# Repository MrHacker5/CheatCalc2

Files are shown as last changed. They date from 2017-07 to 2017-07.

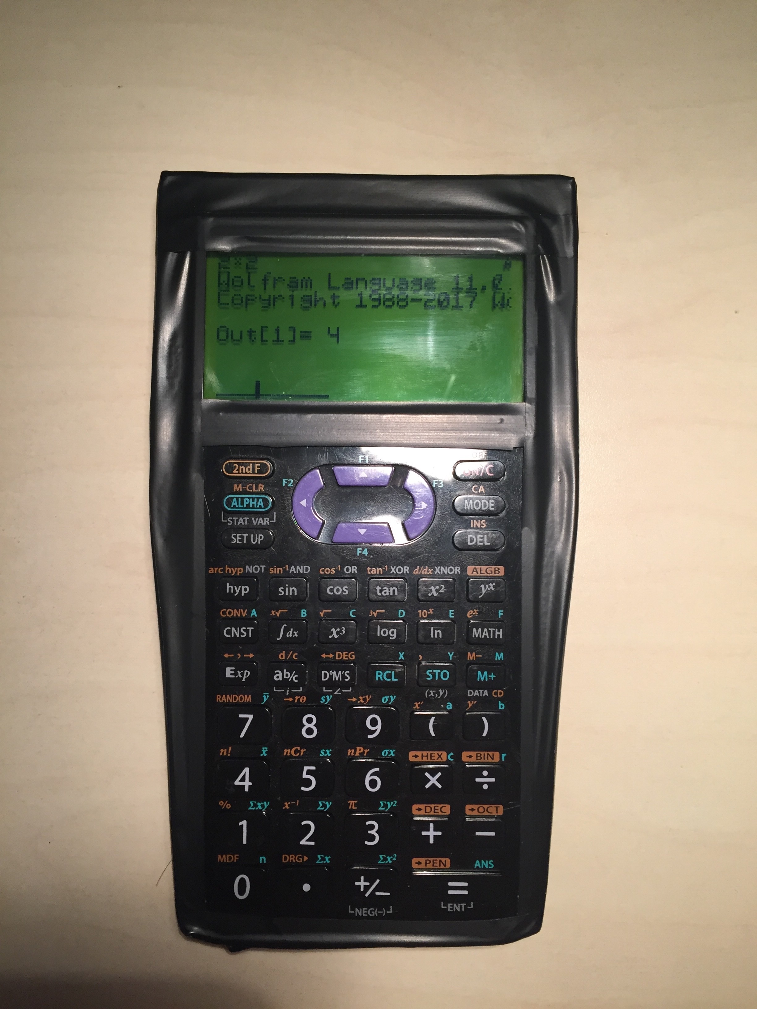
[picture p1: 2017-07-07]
front.JPG

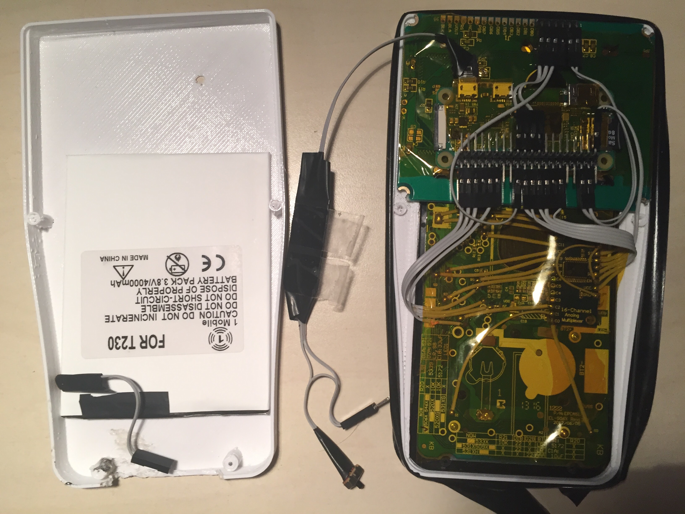
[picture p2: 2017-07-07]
inside2.jpg

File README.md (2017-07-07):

# CheatCalc 2.0
[If the first time ya didn't succeed...](https://github.com/MrHacker5/CheatCalc)

## Features
With this smart calculator you can:  

* solve linear algebra stuff with the help of some macros (ex: eigenSys(m) -> find all eigenvalues and eigenvectors)
* browse input history and use autocompletion
* search previously saved notes by title and tags

## How to build one: Requirements
* Raspberry Pi zero (wireless)
* if you have the rpi zero non wireless you need also a wifi dongle and an OTG adapter
* a calculator with buttons sensors on a PCB (if the sensors are on a plastic sheet, they make too much resistance and the rpi cannot register high signals)
* a graphic LCD (st7920)
* a step-up 3.7V->5V converter
* a Li-Po/Li-ion battery (3.7V)
* a Li-Po battery charger (5->3.7V)
* a multiplexer/demultipllexer 16 to 4
* soldering equipment
* cable-making equipment (ribbon cables, male + female dupont connectors, plastic caps, crimper)
* (angled) male headers
* a 2 state switch
* super glue (cyanoacrylate)
* Kapton (heat resistant) and electrical tape
* a 3D printer to print the calculator case

## Instructions
### Wiring
Extract the pcb from the calculator, desolder the battery holder and isolate the integrated chip on the PCB with a cutter or x-acto knife.  
Follow the circuit paths and map the button layout. It should be equivalent to a grid 4xN (N changes depending of the number of buttons, usually 12-15).  
Connect the PCB pads (if there aren't any, scrape the soldering mask over the circuit paths) corresponding to the paths of the larger side of the grid, to the multiplexer.  
Connect the remaining 4 paths and the input of the multiplexer to the Raspberry Pi. The signal pin of the multiplexer must be grounded.  
Connect the LCD as shown here:  
| LCD pin |  Rpi pin  |  
|  :---:  | :---: |
| RS | 26 (CS0)  |  
| RW | 19 (MOSI) |  
| E | 11 (CLK)  |  
| PSB | GND |  
Please refer to https://github.com/JMW95/pyST7920.  
Connect the Raspberry Pi to the step-up which in turn is connected to the battery (with a switch on the VCC line).  
  
Use the Kapton tape and the electrical tape to isolate the components.  
Print the stl files in the folder `3d files`.

### Installation
You need to use the official distro Raspbian on the Raspberry Pi (this program uses Wolfram Mathematica).  
Install `python3, python-dev, python-rpi.gpio`. Then with pip3 install `pypng`.  
Enable SPI interface with `raspi-config`.  
Clone this repo in the folder `/home/pi/CheatCalc2/`.  
(Optional: download and setup [rclone](https://rclone.org/) to transfer the files from the cloud to the Raspberry.)  
In the file `CheatCalc2/key-layout.txt`:  

* modify the input and output pins according to your wiring
* modify the key function relative to each combination of input-output

Append to `/etc/rc.local` (remember the '&'):  
```sh /home/pi/Cheatcalc2/bootstrap.sh &```  

## Enjoy
Save your own notes in the file `CheatCalc2/notes.txt` and your macros in the file `CheatCalc2/macros.txt`.

## Gallery
![front](/front.jpg?raw=true)
![inside1](/inside1.jpg?raw=true)
![inside2](/inside2.jpg?raw=true)

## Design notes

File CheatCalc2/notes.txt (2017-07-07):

%title: Spazio vettoriale
Un spazio vettoriale e' tale se sono definite le operazioni di somma e prodotto. Es: R2

%title: Sottospazio
%tags: sotto spazio sottoinsieme insieme
Un sottosp di V e' un sottoinsieme U non vuoto di V che e' uno spazio vett per la restrizione delle operazioni si V

%title: Intersezione di sottospazi
Se U e W sono sottospazi di V allora UnW={ v c- V / u c- U e u c- W } e' un sottospazio di V
DIM: UnW  != vuoto perche' contiene 0v sempre. Se v1, v2 c- U n W e alpha, beta c- k
alpha*v1+beta*v2 c- U perche' U e' sottosp
alpha*v1+beta*v2 c- W
quindi appartiene all'intersez, che e' sottosp di V #

%title: Indipendenza lineare
%tags:  vettori indipendenti vett ind
I vett v1...vn di V sono lin ind se a1*v1+...an*vn=0v
quindi a1=a2=an=0
I vett sono dip se uno si puo' scrivere come comb lin dei rimanenti
DIM (=>) v1..vn lin dip se esistono lamb1..lambn tc lamb1v1+..lambn*vn=0v
c'e' qualche lamb_i!=0
lambivi=-lamb1v1-..lambnvn [senza lambivi]
vi=-lamb1/lambi[=a1]*v1-..n=a1v1+..anvn
(<=)...

%title: Base
%tags: generatori indipendenti
base = gen + ind
Oss: Se 'V'={v1...vn} e' una base di V, allora ogni v c- V si scrive in modo unico come comb lin dei vett della base
DIM: V=<v1...vn> quindi dato v c- V esiste a1...an c- K tc v=a1*v1+...an*vn
Se fosse anche v = a1*v1+...an*vn avrei:
0v=v-v=(a1*v1+...an*vn)-(b1*v1+...bn*vn)=(a1-b1)*v1+...(an-bn)*vn
Siccome v1...vn sono ind: a1-b1=...=an-bn=0k #

%title: Equazioni cartesiane
%tags: spazio vettoriale base
Dati v1,...vk base di V sottospazio di Rn, per trovare le eq cart:
Applico le op di Gauss sulla matrice completa (A|b) dove A sono i vettori v messi per riga e b una colonna di coefficienti
Le eq cart sono le espr(=0) corrispondenti alle righe = 0  di A ( quando si arriva a rango minimo)

%title: Teorema di struttura
%tags: dimensioni basi elementi lemma scambio
Ogni sp vett V su K, V!=<0v> ha una base. Due basi di uno stesso sp vett hanno dim uguale. Inoltre V sia finitamente
generato, cioe' esiste un insieme finito di gen per V.
DIM: V!=<0v> 0v non e' lin ind.
Sia V!=<0v> e v1...vn un insieme di gen per V. Ci sono due casi:
- v1...vn sono lin ind -> esiste base #
- v1...vn sono lin dip, quindi a1*v1+...an*vn con non tutti coeff = 0
Posso supporre a1!=0: a1*v1=-a2*vn/a1-...-an*vn/a1  (a1!=0)
Per cui v1 c- <v2...vn> quindi <v2...vn>=<v1,v2...vn>=V
v2...vn sono gen di V, se sono ancora dip ripeto il processo. Siccome V!=<0> quando sono lin ind avro' una base #
DIM due basi hanno uguale dim:
Siano v1...vn e w1...wm de basi di V. In particolare v1...vn sono gen di V e w1... wm sono ind. Per il lemma di scambio m<=n. Ora considero w1...wm gen di V e v1...vn lin ind. Allora per il lemma anche n<=m quindi n=m #

%title: Lemma di scambio
%tags: generatori linearmente indipendenti
Se v1...vn sono gen di V e w1...wr sono vett lin ind allora r<=n. (ogni ins di vett ind puo' essere completato ad una base)
DIM: 0v!=w1 c- <v1...vn>=V
w1=a1*v1+...an*vn con non tutti coeff = 0
A meno di camb l'ordine dei vett v1...vn, supponiamo a1!=0:
v1=w1/a1-a2*v2/a1-...-an*vn/a1
Dunque <w1,v2...vn> _D <v1,v2...vn>=V e percio':
w2 c- V=<w2,v2...vn>
w2=b1*w1+...bn*vn con non tutti coeff=0
a meno di non camb ordine suppongo b2!=0
Quindi v2=w2/b2-b1*w1/b2-b3*w3/b2-...-br*wr/b2
Come prima: V=<w1,v2...vn> c_ <w1,w2,v3...vn> c_ V
overo V=<w1,w2,v3...vn>
Il processo continua fino ad esaurire tutti gli ind w1...wr
Se fosse n<r avrei V=<w1...wn> e w_(n+1) c- <w1...wn> e w1...w_(n+1) sono indipendenti -> assurdo #

%title: Somma di due sottospazi
U+W={u+w/u c- U, w c- W} La somma di sue sottosp e' un sottosp di V ed e' il piu' piccolo sottosp che contiene sia U che W, ovvero U+W=<UuW>
DIM: U+W e' un sottosp perche' non vuoto, 0 c- U, 0 c- W e quindi 0+0=0 c- U+W e dati u1+w1 e u2+w2 in U+W, a1,a2 c- K
a1(u1+w1)+a2(u2+w2)=(a1*u1+a1*w1) [c- U] +(a2*u2+a2*w2) [c- W] c- U+W
Quindi UuW c_ U+W e ogni sottosp che contenga i vett di U e quelli di W, se e' sottosp deve contenere le loro somme #

%title: Somma diretta
%tags: sottospazi
Due sottosp sono in somma diretta se la loro intersezione non e' banale: U1(+)U2 se U1nU2=<0> (!=vuoto)
Ogni vettore U1(+)U2 si scrive in modo unico come somma di un vett di U1 e un vett di U2
DIM: Sia u1+u2=u1'+u2' c- U1(+)U2 con u1,u1' c- U1; u2,u2' c- U2
Allora u1-u1' [c- U1] =u2'-u2 [c- U2]
Cioe' u1-u1'=u2'-u2 c- U1nU2=<0v> perche' un somma diretta
Quindi u1-u1'=0v=u2'-u2
Percio' ui=u1' e u2=u2' #

%title: Formula di Grassmann
Se U e W sono sottosp di uno sp vett V su K: dim(U+W)+dim(UnW)=dimU+dimW
DIM: Sia v1...vr una base di UnW
Per il lemma di scambio posso completare questi vettori ad una base v1...vr,u_(r+1)...us di U; v1...vr,w_(r+1)...wt di W
dim(UnW)=r, dimU=s, dimW=t
v1...vr,u_(r+1)...us,w_(r+1)...wt sono generatori di U+W perche' dato U+W -D u+w=(sum(xn*vn, n=1->r)+sum(xn*un, n=r+1->s))+(sum(yn*vn, n=1->r)+sum(yn*wn, n=r+1->t))=sum((xn+yn)vn, n=1->r)+sum(xn*un, n=r+1->s)+sum(yn*wn, n=r+1->t)
v...u...w sono lin ind perche' dato sum(an*vn, n=1->r)+sum(bn*un, n=r+1->s)+sum(cn*wn, n=r+1->t) = 0
allora [term con a e b = - term con c] => term con b  e c =0 perche' UnW si scrive in modo unico come comb lin di v1...vr
Quindi a1v1+...arvr=0 e' possibile sse tutti gli a=0 perche' v1...vr sono lin ind. Percio' i vett v...u...w sono lin ind.
Quindi v...u...w e' una base di U+W. Percio' dim(U+W)=s+t-r -> dim(U+W)=dimU+dimW-dim(UnW) #

%title: Applicazioni lineari
Se f:V-> W e' lineare allora f(0v)=0w
DIM: f(0v)=f(0v+0v)=f(0v)+f(0v) [f e' lineare]
Sommo -f(0v) ad ambo i membri e trovo 0w=f(0v) #

%title: Isomorfismo
%tags: applicazione lineare biiettiva
Un appl lin e' in isom se esiste un'appl lin g:W->V / f(g(w))=w per ogni w c- W e g(f(v))=v per ogni v c- V
f@g e' l'identita' su w e g@f e' l'identita' su V
isomorfismo<=>biiettiva

%title: Omomorfismo
Applicazione lineare generica.

%title: Endomorfismo
Isomorfismo che ha lo spazio di partenza e di destinazione uguali

%% altro sul pdf 9

%title: Nucleo
%tags: kernel sistema associato
Una base del ker si trova risolvendo il sis associato ad: A*x=0 e assegnando valori arbitrari alle variabili non definite

%title: Proprieta' nucleo e immagine
%tags: kernel
Sia f:V->W appl lin:
- ker f e' sottosp vett di V e Im f e' sottosp vett di W
DIM: 0v c- ker f e se v1, v2 c- ker f e a1,a2 c- KerAf(a1v1+a2v2)=a1(f(v1))+a2(f(v2)) perche' f appl lin
=a1*0w+a2*0w=0w
Dunque a1v1+a2v2 c- ker f = sottosp
0w=f(0v) c- Im f
Se prendo due vett w1,w2 c- Im f e a1,a2 c- K
w1=f(v1), w=f(v2) con v1,v2 c- U1 e quindi a1w1+a2w2 = a1*f(v1)+a2*f(v2)=f(a1v1+a2v2) c- Im f
Quindi f e' sottosp vett #
f e' iniettiva <=> ker f = <0v>
DIM (=>) Se f iniettiva e v!=0v allora f(v)!=f(0v)=0w e quindi ker(f)=<0v> #
(<=) Se f(v1)=f(v2) con v1!=v2 (f non iniettiva) allora f(v1-v2)=f(v1)-f(v2)=0w
quindi 0v!=v1-v2 c- ker f #

%title: Immagine
%tags: rango rk gauss
Le col di A sono i gen della f associata. Una base dell'Im sono i vett corrisp ai pivot trovati con gauss (colonne)
Oppure scelgo ad occhio le colonne lin ind della matrice

%title: Formula delle dimensioni
%tags: kernel immagine nucleo
dim(ker f)+dim(Im f)=dim V
DIM: Siam k=dim(ker f) e siano v1...vk una base di ker f
Completiamo questi vett ad una base v1...vk,v_(k+1)...vn
applicando f ho f(v1)=f(vk)=0w
e siano w_(k+1)=f(vk+1),...,wn=f(vn)
Sia w=f(v) c- Im f con v=x1*v1...xn*vn c- V
Generatori? w=f(sum(xi*vi, i=1->n))=sum(xi*f(vi), i=1->k)[<-barrato] +sum(xi*f(vi), i=k+1->n)=0w
Quindi w c- <w_(k+1)...wn>=Im f
Indipendenti? 0w=a_(k+1)*w...->n= a*f(v) k+1...n=f(a*v, k+1->n)
cioe' a_(k+1)*v...->n c- ker f
e quindi “ =a*v 1->k perche' v1...vk e' base di ker f
dunque v1...vk...vn e' base di V; tutti i coeff sono=0, quindi w_(k+1)...wn ind
Dunque sono base di Im f #

%title: Proprieta' applicazioni lineari
a) Se f:V->W e' lin, f e' univoc det da f(v1)...f(vn)
b) Scelti comunque w1...wn c- W, esiste ed e' unica l'appl lin g:V->W tc g(v1)=w1...g(wn)=wn
DIM a): Sia v c- V. Allora v=x1v1+...xnvn con x1...xn univoc det
Allora f(v)=f(x1v1+...n)=x1*f(v1)+...n
Quindi f(v) e' univoc det dai vett f(v1)...f(vn) #
DIM b): Fissiamo w1...wn c- W consideriamo l'appl che manda v=x1v1+...n c- V in g(v)=x1w1+...xnwn
Devo verif che g sia lin
Se v=x1v1+...n
v'=x1v'1+...n e a,a' c- K
av+a'v'=(ax1+a'x1')v1+...n
g(av+a'v')=(ax1+a'x1')w1+...n=a(x1w1+...n)+a'(x'1w1+...n)=a*g(v)+a'*g(v')
Cioe' g(v1)=w1...g(vn)=wn #

%title: Rango
%tags: rk gauss
rk(A)= dim del sottosp gen dalle col di A =rk(f) (in genere anche =dim(Im f))
rk(AB)<=rk A, rk B
Si puo' trovare con le op di gauss

%title: Nullita'
null(A)=dim(KerA)=dim{x / A*x=0}

%title: Matrice invertibile
matrice A c- Mmxn(K) e' invertibile:
- a dx se esiste B c- Mnxm(K) tc AB=1m; se n<m, rk(AB)<m IMP
- a sx se esiste C c- Mnxm(K) tc CA=1m; se m<n IMP
- invertibile se esiste A^-1 tc A*A^-1=1 o se ker A = <0>; m=n; appartengono al General Linear Group, di ordine n
A nxn non e' invertibile se rk(A)<n

%title: Matrice di cambiamento di base
%tags: canonica
alpha_v'w'(f)=alpha_ww'(id)*alpha_vw(f)*alpha_v'v(id)
id=endomorfismo
Date le basi B={v1...vn} e B'={v'1...v'n}:
Trovare matrice M_B,B':
vj=aj1*v'1+...ajn*v'n per j=1->n. i coeff si trovano risolvendo gli n sistemi (spesso ad occhio).
M_B,B'=[[a11,a21...][a12...]...] (i coefficienti vanno messi per colonna!)
Date la base B e la base canonica C:
M_B,C e' la matrice avente per colonne le coordinate dei vettori di B
M_C,B=(M_B,C)^-1 oppure metodo normale

%title: Operazioni di Gauss
%tags: inversa pivot
Op di Gauss sulle righe equivalgono a cambiamenti di base del codominio
Con le op di gauss sulle righe si puo' trovare l'inversa: (A|1)~(1|A^-1)
Pivot: primo elemento non nullo della riga

%title: Teorema di Rouche'-Capelli
%tags: gauss sistema lineare R-C
Un sis lin si puo' scrivere come (A|b). Con le op di gauss si arriva a (1|s) dove s e' sol particolare e sommato alla comb lin del ker ottengo l'insieme di sol.
Il sis lin Ax=b con A c- M_mxn(K), b c- K^n ha sol <=> rk(A=rk(A|b)
Il sis ha come sol un sottosp di K^n di dim=n-rk A. La sol di un sis lin e' un sottosp vett <=> Il sistema e' omogeneo (b=0)
DIM: Risolvere il sis Ax=b significa trovare S={gamma c- K^n / f(gamma)=b}=f^-1(b) cioe' controimmagine di b
Allora S= (vuoto se b non c- im f) or (se gamma0 c- K^n e' tc f(gamma0)=b allora S=gamma0+ker f)
Se ker(f)=0 e b c- Im f il sis ha 1 sol
Im f c_ K^n e' il sottosp gen dalle col di A
Quindi b c- Im f <=> rk A=rk(A|b) #

%% pdf 20 domande a risp aperta

%title: Determinante
%tags: gauss laplace
E' una funzione multi-lineare;
- si annulla se 2 colonne sono uguali
- matrice id -> =1
- se e' !=0 la mat e' invertibile (rk max)
- det A=det(A^t)
- det(mat triang)= prodotto termini diagonale
Formula di Laplace:
det A= sum(a_ij*(-1)^(i+j) *det(A_ij), j=1->n)
Op di gauss:
- scambio due righe -> det * -1
- moltipl riga per scalare c -> det * c
- somma di righe -> det invar

%title: Teorema di Binet
%tags: determinante
det(AB)=det A * det B

%title: Matrice inversa
%tags: gauss complemento algebrico
Con gauss: (A|1)~(1|A^-1)
Con il det: (A*^t)/det A
Compl agebrico a*_ij: (-1)^(i+j) * det(A_ij) con A_ij la matrice A senza riga i e col j

%title: Matrici simili
%tags: polinomio caratteristico
A, B quadrate sono simili se esiste P c- GLn(K) tc B=P^-1*A*P
Se A e B sono simili allora hanno lo stesso pol. caratt.: det(x*1n-A)=det(x*1n-B)
DIM:det(x*1n-B)=det(x*1n-P^-1*AP)=det(x*P^-1*1nP-P^-1*AP)=det(P^-1 (x1n-A)P)=[binet] det(P^-1) [barrato] det(x1-A) detP [barrato] #

%title: Matrice diagonale
Matrice aventi termini non nulli solo sulla diagonale

%title: Autovalori e autovettori
%tags: matrice diagonale autospazi molteplicita'
Sia V sp vett di dim n e phi:V->V lin
Uno scalare a c- K e' autovalore per phi se esiste un vett v!=0 tc phi(v)=a*v
In tal caso v e' autovettore per phi relativamente ad a
Gli autovettori/autospazi si trovano con ker(A-a*id)=0 dove a e' l'autovalore
Proprieta':
a) autovett di phi relativi ad autoval distinti sono lin ind (ker(phi-a1*id)+...ker(phi-an*id)=0v)
b) per ogni autoval a di phi: m_g(a)<=m_alg(a)
DIM a): Siano v1...vr autovett rel ad a1...ar (a2a2 distinti)
Sia c1v1+...crvr=0v
e Applichiamo (phi-a1*id) ai due membri:
c1(phi(v1)-a1*id*v1)+...cr(phi(vr)-a1*id*vr)=0v
c1(a1-a1)[barrato]*v1+...cr(ar-a1)vr=0
Applico phi-a2,...phi-a_(r-1) e trovo
cr(ar-a1)[!=0]*...(ar-a_(r-1))[!=0][!=0 perche' sono autoval distinti]*vr[!=0]=0
quindi cr=0
Analogamente c1...c_(r-1)=0
DIM b) Sia a autoval per phi e siano v1...vk base di ker(phi-a)={v c- V / phi(v)=a*v}
1<=m_g(a)=k
completiamo i vettori a v1...vk,v_(k+1)...vn base di V
A=alpha_'V''V'(phi)=
(a .. 0 |  )
(...... | B)
(0 .. a |  )
--------+---
(0 .. 0 | C)
P_phi(x)=det(x*1n-A)=det di:
(x-a .. 0|   )
(........| -B)
(0 .. x-a|   )
---------+----
(0 .... 0|x-C)
[x-C ha di (n-k)*(n-k)]
=(x-a)^k*phi(x)
Allora m_alg(a)>=k=m_g(a) #

%title: Matrice diagonalizzabile
%tags: diagonale endomorfismo autovettori autovalori
A c- Mn(K) si dice diagonaliz se esiste una P c- GLn tc P^-1*A*P=D (diagonale)
P e' formato dagli autovett messi in colonna
D e' formato dagli autoval messi sulla diagonale
Un endomorf phi:V->V si dice diagonaliz se esiste una base di V fatta di autovett per phi

%title: Teorema di Freobernius
%tags: molteplicita' algebrica geometrica
Sia V sp vett di dim finita su K e ph:V->V lin
Allora phi e' diagonaliz su K <=> gli autovalori di phi sono tutti in K o per ogni autoval a m_g(a)=m_alg(a)
DIM: Siano a1...ar autoval  a due a due distinti di phi
ker(phi-a1) (+)...(+) ker(phi-ar) c_ V
ha dimensione: mg(a1)+...mg(ar) [ogni termine <= a] ma(a1)+...ma(ar)=dimV #

%title: Prodotto scalare
E' una funzione bilineare e definita positiva

%title: Disuguaglianza di Cauchy-Schwartz:
Se v e w sono vett di R^n allora |v.w|<=||v||*||w||
l'uguaglianza vale <=> v,w sono lin ind
DIM: Se uno dei due e' =0 #
se entrambi !=0 e il vett v+t*w, t c- R allora:
0<=(v+tw)(v+tw)=v.v + 2T(v.w)+t^2(w.w)
0>=delta/4=(v.w)^2-(v.v)(w.w)
allora ||v||^2*||w||^2>=|v.w|^2
cancellando i quadrati -> #

%title: Disuguaglianza triangolare
||x+y||<=||x||+||y||
DIM: ||x+y||^2=(x+y)(x+y)=x.x+2xy+y.y=||x||^2+||y||^2+2xy<=...+2|xy|<=[C-S] ... +2*||x||*||y||=(||x||+||y||)^2
cancellando i quadrati -> #

%title: Vettori ortogonali
%tags: perpendicolari prodotto scalare
v, w c- R^n sono ortog se v.w=0
Se v c- R^n: V^perp={w c- R^n : w.v=0, perogni v c- V} e' sottosp vett di R^n
DIM: siano w1,w2 c- V^perp e alpha1, alpha2 c- R
(a1*w1+a2*w2).v=a1(w1.v)+a2(w2.v)=a1*0+a2*0=0
percio' V^perp e' sottosp #
Vale anche per gli spazi vett
Se W e' sottosp di Rn di dim k allora dim_R(W^perp)=n-k
DIM: Siano w1...wk base di W
w1=(a11...an1)...wk=(a1k...ank)
x=(x1...xn) c- W^perp <=>
/{x.w1=0
...
\{x.wk=0
[sviluppo sistema]
per il T di R-C la dim di W^perp e' n-rk{mat degli a}=n-k perche' w1...wk sono lin ind #
Conseguenza: (W^perp)^perp=W

%title: Teorema di decomposizione ortogonale
%tags: grassmann somma diretta perpendicolari
Preso comunque un sottosp W di R^n:
R^n=W(+)W^perp
DIM: Sia k=dim_R(W). Dunque n-k=dim(W^perp) [vedi DIM in “vettori orogonali”] e per la formula di grassman e' sufficiente DIM che WnW^perp=<0>
Se x c- WnW^perp: x.x=0 => x=0 #

%title: Base ortogonale e ortonormale
Una base ortogonale in W c- Rn e' una base w1...wk c- W dove i vett sono a due a due ortogonali
Una base ortonormale e' una base ortogonale di W tc ||w1||...||wk||=0
Se 'V'={v1...vn} e' base O.N. in R4
P=alpha_'V''E'(id) allora:
1n=P^t*P; P^t=P^-1
Una matrice quadrata P c- Mn(R) e' perp se “
Quindi le colonne di P sono le coord di una base O.N. di Rn
Vale anche per prodotto di matrici
Inoltre det P=+-1 (dipende dall'handing)

%title: Proiezione ortogonale
Sia v c- Rn e W sottosp di Rn.
per ogni vett w c- W si ha: ||v-P_w(v)||<=||v-w||
Ovvero la proiez ortog e' il vett di W che ha la minima differenza da v
DIM: Sia P_w(v) la proj ortog di v su w e w c- W
Allora v-w=(v-Pw(v)) +(Pw(v)-w)[c- W]
Quindi ||v-w||^2=||v-Pw(v)||^2+||Pw(v)-w||^2+ 2(v-Pw(v)) [c- Wperp] *(Pw(v)-w)[c- W][=0] >=||v-Pw(v)||^2 #
La proj. ortog. di un vettore su un sottospazio: sommo le proj. ortog. del vett. sui vettori della base del sottosp.

%title: Vettori ortogonali
%tags: perpendicolari
Se u1...uk sono vett di Rn non nulli e adue a due ortog allora u1...uk sono lin ind
DIM: Sia a*u+...ak*uk=0_Rn
Allora 0=u1.(a1u1+...akuk)=a1*(u1.u1)[!=0] +a2(u1.u2) [barrato] ... k -> a1=0
Analogamente verifico che a2...ak=0 #

%title: Procedimento di Gram-Schmidt
%tags: vettori ortogonali
Data una base u1...uk si puo' ottenere una base ortogonale w1...wk:
- w1=u1
- wi=ui-sum((vi.wj)*wj/(wj.wj), j=1->i-1) con i=1->n

%title: Teorema spettrale di Cauchy
Sia f:Rn->Rn appl lin e sia A=alpha_EE(f) [oppure qualsiasi base O.N.], esiste una base O.N. di autovettori per f <=> A^t=A [A simmetrica]
DIM: (=>) Sia 'V'={v1...vn} base O.N. di autovett per f e siano:
A=alpha_EE(f) e D=alpha_'V''V'(f) e' diagonale
P=alpha_'V'E(f) ortogon P^t*P=1n
Si ha: A=PDP^-1=PDP^t (perche' P e' ortog)
Allora A^t=(PDP^t)^t=PDP^t=A perche' D e' diagonale #
(<=) Sia f:Rn->Rn con A=apha_EE(f)=A^t (simmetrica)
- tutti gli autoval di A sono reali:
Sia apha un autoval di f
Sia v un autoval rel ad alpha
conj(v)..............

%% todo: DIM T. spettrale!!!!! pdf 29

%title: Prodotto vettoriale
%tags: 3D
v x w:=(v2w3-v3w2, v3w1-v1w3, v1w2-v2w1)
Il produtto non ha propr commutativa e associativa
Vale solo per spazio 3D

%title: Identita' di Lagrange
%tags: prodotto scalare vettoriale
||v x w||^2+(v.w)^2=||v||^2*||w||^2
||v x w||=||v||*||w||*|sin alpha|
l'id di L. e' l'area del parallelogramma

%% todo: DIM + generalizzata

%title: Generalizzazione del prodotto scalare
Le generaliz sono appl: g:Rn x Rn->R ; (v,w)|-->g(v,w)
- bilineari: g(av+a'v',w)=a*g(v,w)+a'*g(v',w)
- simmetriche g(w,v)=g(v,w)
Si dividono in: [g(v)]
- triviali (sempre 0)
- Positiva se positiva se v non nullo
- Negativa se negativa se v non nullo 

%title: Teorema di Silvester
%tags: prodotto scalare bilineare simmetrica somma diretta
Se g:RnxRn->R e' appl bilin simm allora esistono dei sottosp W0, W+, W- di Rn tc:
Rn=W0(+)W+(+)W-
e a2a2 ortogonali tc:
g ristretta a W0W0 e' triviale; “ W+W+ e' positiva; “ W-W- e' negativa

%title: Identita' di Jacobi
%tags: prodotto vettoriale scalare
u.(vxw)+vx(wxu)+w(uxv)=0

%title: Teorema di Jacobi
%tags: prodotto scalare matrice gram
Sia la matrice di Gram:
G=((g(x1,x1)...g(x1,xn))...(g(xn,x1)...g(xn,xn)))
dove g e' funzione bilineare simmetrica
Sia delta1=g11, delta2=g11*g22-g12^2... deltan=det G
G e' definita positiva se ogni delta>0: negativa se ogni delta<0; non definita se det G !=0

%title: Sottovarieta' lineare
%tags: spazio affine grassman unione somma
L=0+W={P0+w / w c-W}
dive P0 c- L e W e' sottosp reale di V
In particolare il vuoto e' una sottovar lin
dim L:=dim W
Due sottovar lin L=P+W, M=Q+U si dicono:
- incidenti se LnM!=0
- parallele se W c_ U o U c_ W
- sghembe se LnM=vuoto e UnW=<0> (in questo caso Q-P c/- U(+)W
Vale la formula di Grassman per le dimensioni se LnM!=0 ovvero paralleli
dim(LvM)=dim L + dim M - dim(LnM)
Date due sottovar lin LvM e' la piu' piccola sottovar lin che contiene LuM e se L=P+U e M=Q+W
LvM=P+(<Q-P>+U+W)
- (U+W)^orto=U^orto n W^orto
Oss: LnM!=0<=>Q-P c- U+W
DIM: (=>)
Sia P0 c- LnM
allora P+u0=P0=Q+w0
Per cui P+u0-w0=Q
e allora Q-P=u0-w0 c- U+W
(<=)
Sia Q-P=u1+w1
Applicando questo vett in P trovo
Q=P+(Q-P)=P+u1+w1
e sommando ad entrambi i membri il vett -w1 trovo
Q-w1[c- M]=P+u1[c- L] c- LvM #

%title: Distanza minima tra sottovarieta'
Prendo Q=Q0+w0 c- M
e P=P0-u0 c- L
Allora Q-P=n c- U^orto n W^orto -> il vett differenza e' perp a tutte e 2 le varieta'
Questi 2 punti hanno dist min
DIM: Sia X c- L e Y c- M
X=P+u esiste u c- U
Y=Q+w esiste w c- W
||X-Y||^2=(Q-P+w-u)^2=(n[vedi sopra]+(w-u))*([=])=||n||^2+||w-u||^2>=||n||^2=||Q-P||^2

%title: Spazio euclideo
%tags: spazio affine base ortonormale
E^n=A^n(R) con il prodoto scalare
Le coord sono riferite a base O.N. (spesso canonica)

%% altro sul pdf 37

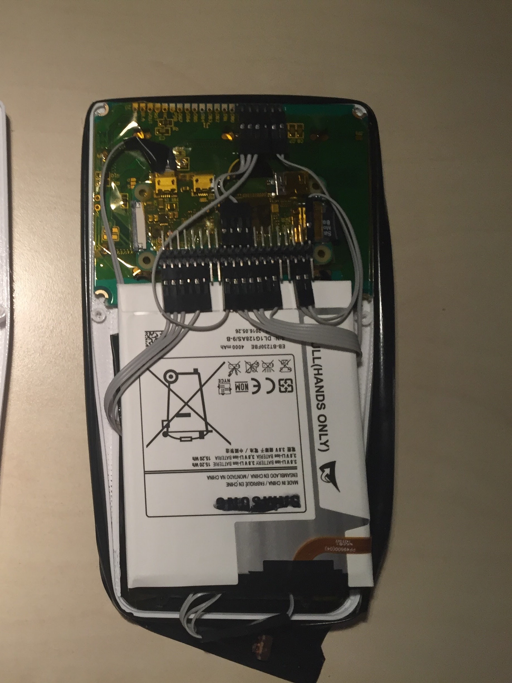
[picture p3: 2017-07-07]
inside1.jpg

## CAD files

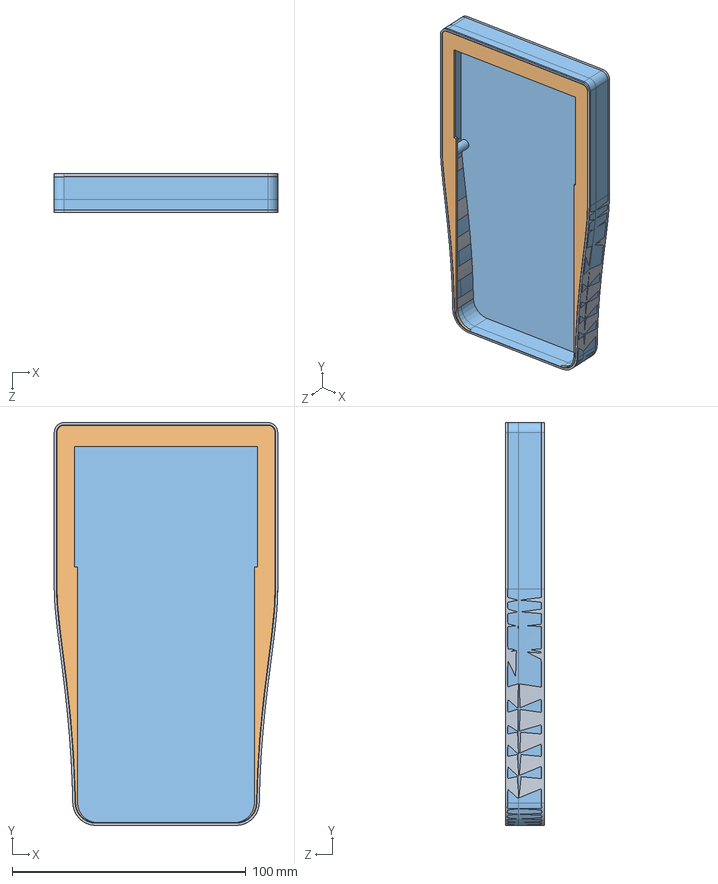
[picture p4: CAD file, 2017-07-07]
3d files/Assem1.SLDASM
95.7 x 172.5 x 16.7 mm

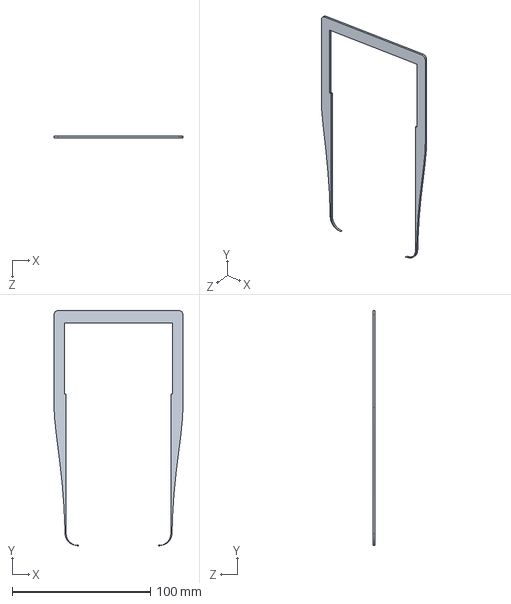
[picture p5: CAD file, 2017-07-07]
3d files/Part3.SLDPRT
93.3 x 170.1 x 1.50 mm

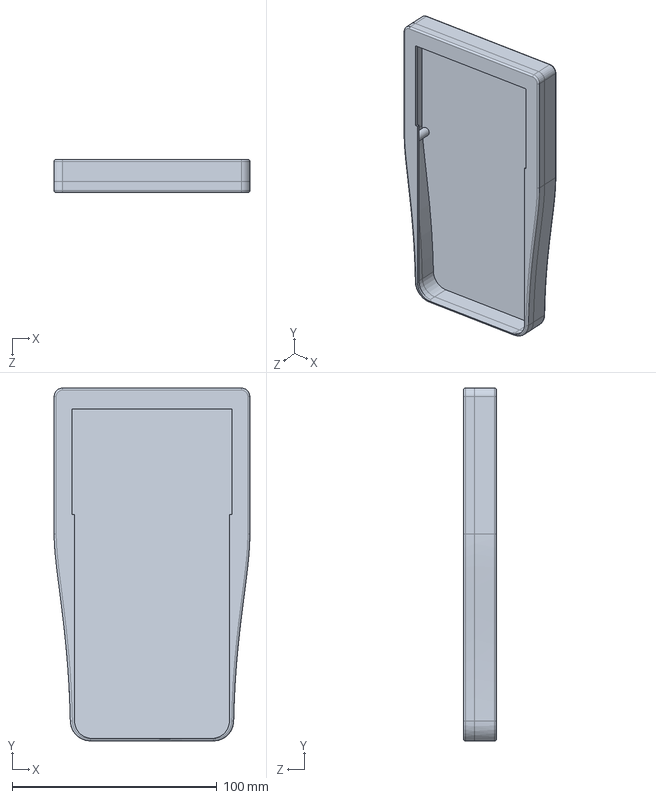
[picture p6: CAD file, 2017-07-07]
3d files/joined.sldprt
95.7 x 172.5 x 16.3 mm

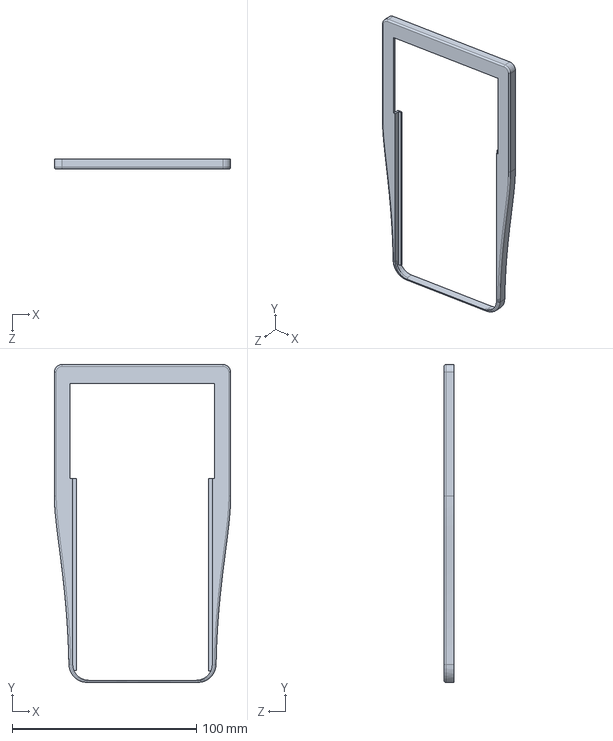
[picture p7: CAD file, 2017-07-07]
3d files/Lid.sldprt
95.7 x 172.5 x 5.50 mm

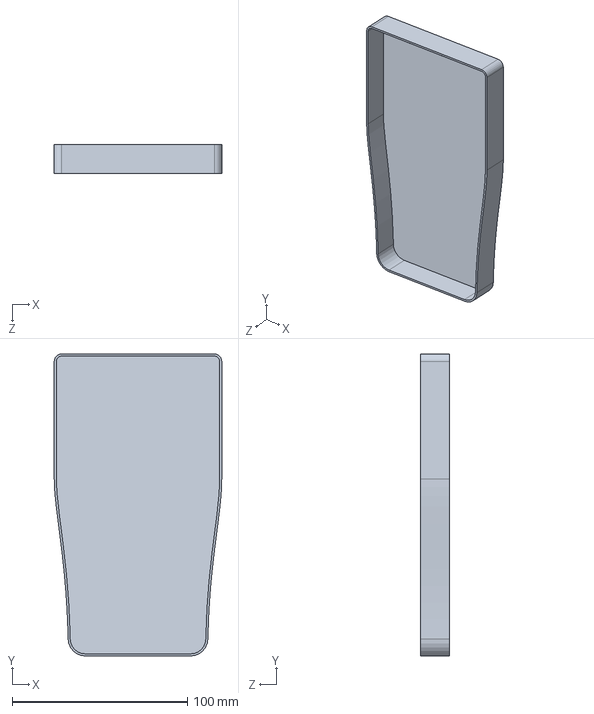
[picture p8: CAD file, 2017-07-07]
3d files/Part1.SLDPRT
95.7 x 172.5 x 16.7 mm

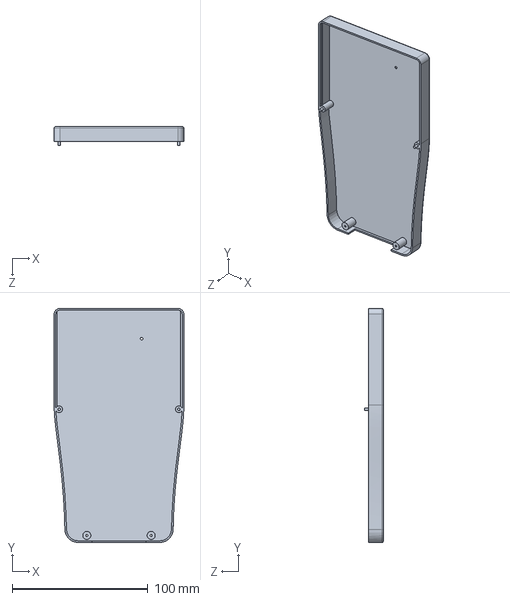
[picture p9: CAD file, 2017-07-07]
3d files/Container.sldprt
95.7 x 172.5 x 13.8 mm

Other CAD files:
3d files/Container.STL
3d files/Lid.STL

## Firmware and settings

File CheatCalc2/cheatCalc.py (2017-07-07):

from time import perf_counter, sleep
import threading
import RPi.GPIO as io
import modules as m
import modules.graphics as g
from modules import parser, TType, Rect, LCD_WIDTH, LCD_HEIGHT, CHAR_WIDTH, CHAR_HEIGHT
from modules.ui import InputField2, Window, List2, Math2, Notes2, Text, Choice


K_REP_THRESH = 0.7
PRSD_THRESH = 0.15


class _cc:
    inPins, outPins, keys = parser.parse_key_layout()
    nKeys = len(keys)
    oldKey = -1
    lastTime = 0
    lastPrsdTime = 0
    oldValidKey = -1
    actCnt = 0
    token = ('', TType.text)
    waiting = False
    thr = None
    gthread_alive = True


def clean_wins():
    idx = len(m.WINDOWS)
    while idx > 0:
        idx -= 1
        if m.WINDOWS[idx].name in ['math', 'notes']:
            m.WINDOWS[idx].setActive(False)
        else:
            w = m.WINDOWS.pop(idx)
            w.close()


def activate_win(name):
    clean_wins()
    for w in m.WINDOWS:
        if w.name == name:
            w.setActive(True)


def restart():
    m.ALIVE = False


def shutdown():
    # close process
    f = open('shutdown.txt', mode='w')
    f.close()
    m.ALIVE = False


def proc_token():
    """under certain circumstances, this is called twice per cicle, most of the time not at all"""
    ttype = _cc.token[0]
    if ttype == TType.sf:
        m.SFUNC = not m.SFUNC
    elif ttype == TType.alpha:
        m.ALPHA = not m.ALPHA
    elif ttype in [TType.shift, TType.caps]:
        m.SHIFTCAPS = 0 if m.SHIFTCAPS != 0 else (
            1 if ttype == TType.shift else 2)
    elif ttype == TType.mode:
        which = False
        for w in m.WINDOWS:
            if w.name == 'math' and w._active:
                which = True
        clean_wins()
        for w in m.WINDOWS:
            if w.name == ('notes' if which else 'math'):
                w.setActive(True)
    elif ttype == TType.reset:
        #clean_wins()
        #fakeinp = InputField2(None, lambda x: activate_win('math'))
        #for c in fakeinp.ctrls:
        #    if type(c) != Text:
        #        fakeinp.removeCtrl(c)
        #fakeinp.addCtrl(
        #    Text(Rect(0, 0, LCD_WIDTH, LCD_HEIGHT - CHAR_HEIGHT), [''], False, False))
        #m.WINDOWS.append(fakeinp)
    elif ttype == TType.shutdown:
        clean_wins()
        m.WINDOWS.append(
            Choice(['Shutdown?'], [('No', lambda: activate_win('math')),
                                   ('Shutdown', shutdown), ('Restart', restart)]))
    elif ttype == TType.meta:
        startDrawThread()
    else:
        for w in m.WINDOWS:
            w.procToken(_cc.token)
    if ttype != TType.sf:
        m.SFUNC = False
    if ttype != TType.shift and m.SHIFTCAPS == 1:
        m.SHIFTCAPS = 0

    print(ttype, _cc.token[1])


# one input line is defective: i must reject repeated key faster than 0.1s
def proc_keys_state():
    """this function detect key press based on duration and discard glitches
    then chooses the right token based on timing and key repetition"""
    currkey = -1
    # get physical key
    old_out_pin = -1
    for k in range(_cc.nKeys):
        _, _, _, in_pin, out_pin = _cc.keys[k]
        if out_pin != old_out_pin:
            old_out_pin = out_pin
            b = m.dec2bin(out_pin)
            for i in range(4):
                io.output(_cc.outPins[i], not b[i])
        if not io.input(_cc.inPins[in_pin]):
            currkey = k
    if currkey != -1:
        if m.TIMENOW - _cc.lastPrsdTime > PRSD_THRESH:
            _cc.lastPrsdTime = m.TIMENOW
            if currkey != _cc.oldKey:
                if _cc.waiting:
                    if _cc.oldValidKey == currkey:
                        _cc.actCnt += 1
                    else:
                        proc_token()
                        _cc.actCnt = 0
                        _cc.waiting = False
                kmode = 1 if m.SFUNC and len(_cc.keys[currkey][1]) > 0 else 2 if m.ALPHA and len(
                    _cc.keys[currkey][2]) > 0 else 0
                l = len(_cc.keys[currkey][kmode])
                if l > 0:
                    _cc.token = _cc.keys[currkey][kmode][_cc.actCnt % l]
                    if l == 1:
                        proc_token()
                    else:
                        _cc.waiting = True
                _cc.oldValidKey = currkey
                _cc.lastTime = m.TIMENOW
    elif _cc.waiting and m.TIMENOW - _cc.lastTime > K_REP_THRESH:
        proc_token()
        _cc.actCnt = 0
        _cc.waiting = False
    _cc.oldKey = currkey


def graphics_thread():
    while m.ALIVE and _cc.gthread_alive:
        for w in m.WINDOWS:
            w.draw()
        x1 = LCD_WIDTH - 4
        if m.SFUNC or m.ALPHA:
            char = '\xfc' if m.SFUNC else '\xfd'
            for x in range(4):
                for y in range(8):
                    g.draw_char_dot(char, x1 + x, y, x, y)
        else:
            g.fill_rect(x1, 0, LCD_WIDTH, 8, False)
        if m.SHIFTCAPS > 0:
            char = '\xfe' if m.SFUNC else '\xff'
            for x in range(4):
                for y in range(7):
                    g.draw_char_dot(char, x1 + x, y + 7, x, y)
        else:
            g.fill_rect(x1, 7, LCD_WIDTH, 14, False)
        g.updInvalRows(0, 14)

        g.fill_rect(m.CUR_POS.x - 1, m.CUR_POS.y,
                    m.CUR_POS.x + 1, m.CUR_POS.y + CHAR_HEIGHT)
        g.redraw()


## INIT ##
g.clear()

# GPIO setup
io.setwarnings(False)
io.setmode(io.BOARD)
for i in range(4):
    io.setup(_cc.inPins[i], io.IN, pull_up_down=io.PUD_UP)

for i in range(4):
    io.setup(_cc.outPins[i], io.OUT)

m.WINDOWS = [Notes2(), Math2()]


def startDrawThread():
    clean_wins()
    if _cc.thr != None:
        _cc.gthread_alive = False
        _cc.thr.join(5.0)
    _cc.gthread_alive = True
    _cc.thr = threading.Thread(target=graphics_thread)
    _cc.thr.start()
    activate_win('math')


startDrawThread()

##### MAIN LOOP #####
while m.ALIVE:
    m.TIMENOW = perf_counter()

    proc_keys_state()

    for w in m.WINDOWS:
        w.loop()

## RELEASE ##
for w in m.WINDOWS:
    w.close()
_cc.thr.join(10.0)

g.clear()
g.draw_text('  Shutting down...', 0, 28)
g.updInvalRows(0,LCD_HEIGHT)
g.redraw()

g.close()
io.cleanup()

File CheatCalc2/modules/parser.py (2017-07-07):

from enum import IntEnum
from collections import namedtuple
from . import isInt, TType, relat_path, CHAR_WIDTH, CHAR_HEIGHT, LCD_WIDTH
import png


class KMode(IntEnum):
    norm = 0
    sf = 1
    alpha = 2


def parse_key_layout():
    lines = open(relat_path('../key-layout.txt')).read().splitlines()
    tkns = [l.split() for l in lines]
    in_pins = [int(tkns[0][i]) for i in range(1, 5)]
    out_pins = [int(tkns[1][i]) for i in range(1, 5)]

    keys = []
    for i in range(len(lines)):
        if len(tkns[i]) == 0 or not isInt(tkns[i][0]):
            continue
        in_pin = int(tkns[i].pop(0))
        out_pin = int(tkns[i].pop(0))
        keys.append(([], [], [], in_pin, out_pin))

        kmode = KMode.norm
        for tkn in tkns[i]:
            if tkn == '%':
                kmode = KMode.sf
            elif tkn == '@':
                kmode = KMode.alpha
            else:
                ttype = TType.text
                if tkn.startswith('%'):
                    tkn = tkn[1:]
                    if '@' != tkn != '%':
                        ttype = TType[tkn]
                elif '@' in tkn:
                    ttype = TType.func
                keys[-1][kmode].append((ttype, tkn))
    keys.sort(key=lambda x: x[4]) #sort by out code
    return in_pins, out_pins, keys
#keys: [([(ttype, ttext)], [(ttype, ttext)], [(ttype, ttext)], inp, out)]


def parse_notes():
    lines = open(relat_path('../notes.txt'),
                 encoding='utf-8').read().splitlines()
    notes = []
    comment = False
    for l in lines:
        tkns = l.split()
        if len(tkns) > 0:
            if tkns[0].startswith('%title'):
                notes.append([l[len(tkns[0]):].strip(), [], []])
            elif tkns[0].startswith('%tags'):
                notes[-1][1] = tkns[1:]
            elif tkns[0].startswith('%%%'):
                comment = not comment
            elif not comment and not tkns[0].startswith('%%'):
                notes[-1][2] += [l[i:i + LCD_WIDTH // CHAR_WIDTH - 1]
                                 for i in range(0, len(l), LCD_WIDTH // CHAR_WIDTH - 1)]
    return notes
# [(title, [tags], [body])]


def parse_macros():
    lines = open(relat_path('../macros.txt')).read().splitlines()
    macros = []
    for l in lines:
        tkns = l.split()
        if len(tkns) > 0:
            first = tkns[0]
            if first.startswith('%'):
                continue
            idx = first.find('(') + 1
            name = first[:idx - 1]
            params = []
            while True:
                newidx = first.find(',', idx)
                if newidx == -1:
                    params.append((first[idx:len(first) - 1], []))
                    break
                params.append((first[idx:newidx], []))
                idx = newidx + 1
            params = [x for x in params if x[0] != '']
            idx = 0
            string = l[l.find(tkns[1]):]
            while idx < len(string):
                paridx = [x for x in range(len(params))
                          if string[idx:].startswith(params[x][0])
                          and (idx == 0 or not string[idx - 1].isalnum())
                          and (idx + len(params[x][0]) >= len(string)
                               or not string[idx + len(params[x][0])].isalnum())]
                if len(paridx) == 0:
                    idx += 1
                    continue
                paridx = paridx[0]
                params[paridx][1].append(idx)
                parlen = len(params[paridx][0])
                string = string[:idx] + string[idx + parlen:]
            macros.append((name, params, string))
    # generate matrix macros
    for y in range(1, 7):
        for x in range(1, 7):
            name = '@' + str(y) + str(x)
            params = []
            string = ''
            for y1 in range(y):
                string += ',' if y1 > 0 else '{'
                for x1 in range(x):
                    string += ',' if x1 > 0 else '{'
                    params.append(('', [len(string)]))
                string += '}'
            string += '}'
            macros.append((name, params, string))
    return macros
# macros: [(name, [(param name, pos)], string)]


def parse_fontsheet():
    img = png.Reader(relat_path('../fontsheet.png')).read()
    rows = list(img[2])
    height = len(rows)
    width = len(rows[0])
    sheet = []
    for y in range(height // CHAR_HEIGHT):
        for x in range(width // CHAR_WIDTH):
            char = []
            for sy in range(CHAR_HEIGHT):
                char.append(rows[y * CHAR_HEIGHT + sy]
                            [x * CHAR_WIDTH:(x + 1) * CHAR_WIDTH])
            sheet.append(char)
    return sheet
